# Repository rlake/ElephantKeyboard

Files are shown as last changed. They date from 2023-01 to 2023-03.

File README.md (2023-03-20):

# Elephant Keyboard
USB-C Number Pad Mechanical Keyboard

Featuring hot-swap Kailh sockets and RGB LED lighting.

Based on [Adafruit KB2040](https://www.adafruit.com/product/5302)

Keyboard Layout
---------------

Number pad from [Keyboard Layout Editor](http://www.keyboard-layout-editor.com)

```
["Num Lock","/","*","-"],
[{a:4,f:3},"7\nHome","8\n↑","9\nPgUp",{h:2},"+"],
["4\n←","5","6\n→"],
["1\nEnd","2\n↓","3\nPgDn",{h:2},"Enter"],
[{w:2},"0\nIns",".\nDel"]
```

Panel from [Swill Plate & Case Builder](http://builder.swillkb.com)

Options:
* mx t3
* cherry only
* edge padding 2.5mm
* corners 2.5mm

Firmware
--------

Based on [KMK](https://github.com/KMKfw/kmk_firmware)

With the following CircuitPython versions:

```
adafruit-circuitpython-adafruit_kb2040-en_GB-7.3.3.uf2
adafruit-circuitpython-bundle-7.x-mpy-20230129.zip
```

And these library files in `lib`:

```
adafruit_pixelbuf.mpy
neopixel.mpy
```

Parts
-----

* 0805 500R resistor QTY 1 (YAGEO RC0805JR-07470RL)
* 0805 100nF capacitor QTY 18 (YAGEO CC0805KRX7R9BB104)
* SC-70-5 level shifter buffer QTY 1 (TI SN74LV1T34DCKR)
* SOD-123 diode QTY 17 (ST 1N4148W)
* Kailh hot-swap sockets QTY 17 (CPG151101S11) [AdaFruit](https://www.adafruit.com/product/4958)
* Neopixel LEDs QTY 17 (SK6812MINI-E) [AdaFruit](https://www.adafruit.com/product/4960)

Plus KB2040 and any mechanical pieces for case i.e. bumpers (3M SJ-5312) and user choice of key caps and switches etc.

Panel was laser cut and powder coated 0.063" 5052 Aluminium by [SendCutSend](https://sendcutsend.com)

Other case parts laser cut 0.118" Acrylic, 0.030" chipboard and powder coated 0.063" 5052 Aluminium.

And finally 12mm M3 nylon or plastic nuts and bolts.

Build
-----
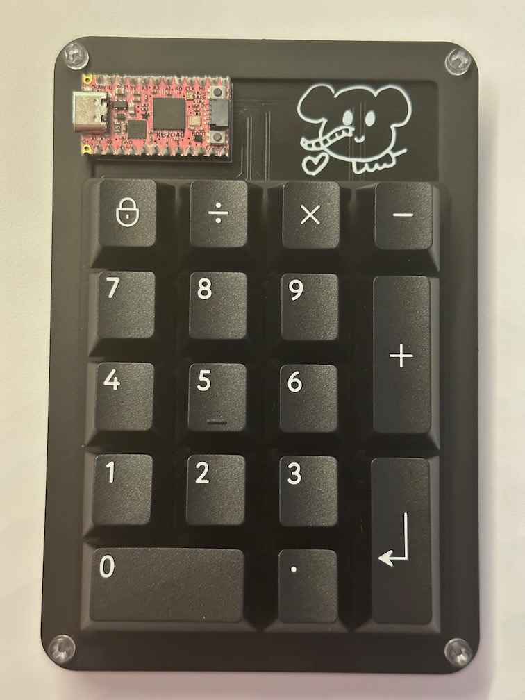
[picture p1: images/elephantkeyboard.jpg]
Elephant Keyboard


License Information
-------------------
The hardware is released under [Creative Commons ShareAlike 4.0 International](https://creativecommons.org/licenses/by-sa/4.0/).

Distributed as-is; no warranty is given.

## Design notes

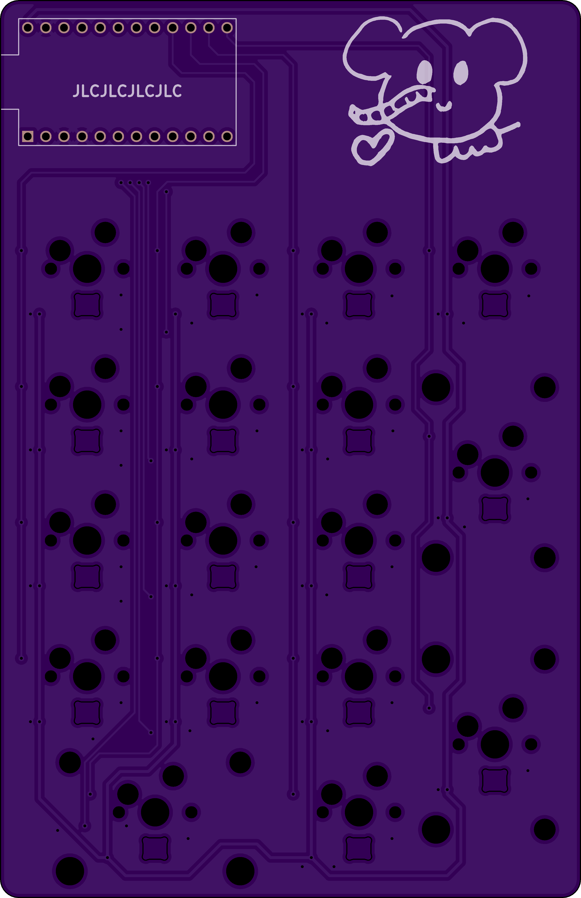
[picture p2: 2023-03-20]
images/elephantkeyboardt.png

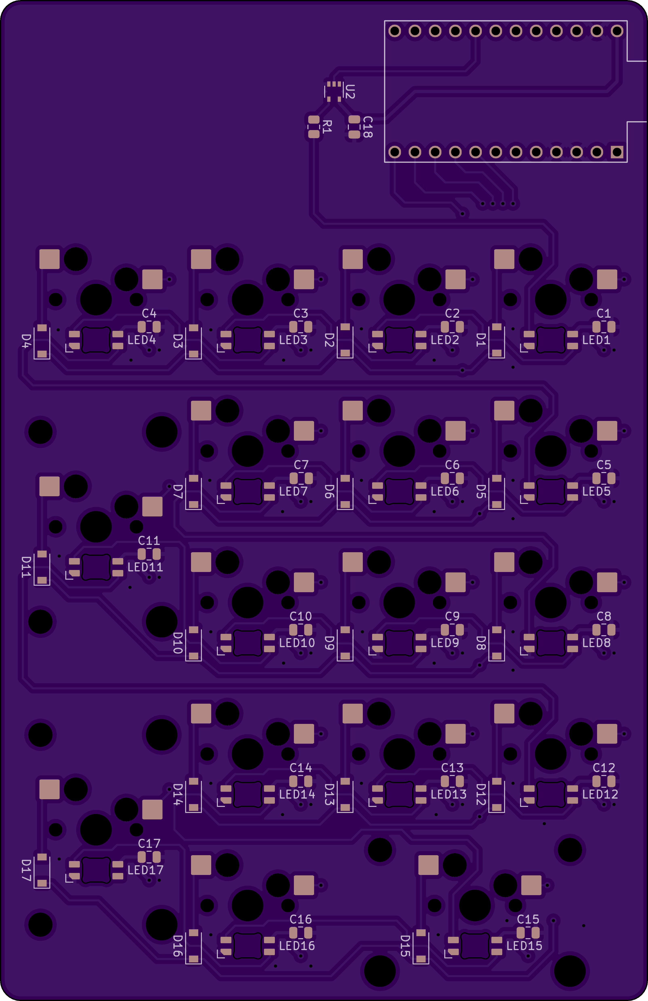
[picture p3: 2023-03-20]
images/elephantkeyboardb.png

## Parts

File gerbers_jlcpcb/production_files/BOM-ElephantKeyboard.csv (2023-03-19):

Comment | Designator | Footprint | LCSC
500R | R1 | R_0805_2012Metric | C114747
100nF | C1,C10,C11,C12,C13,C14,C15,C16,C17,C18,C2,C3,C4,C5,C6,C7,C8,C9 | C_0805_2012Metric | C49678
SN74LV1T34DCK | U2 | SOT-353_SC-70-5 | C78541
1N4148 | D1,D10,D11,D12,D13,D14,D15,D16,D17,D2,D3,D4,D5,D6,D7,D8,D9 | D_SOD-123 | C81598

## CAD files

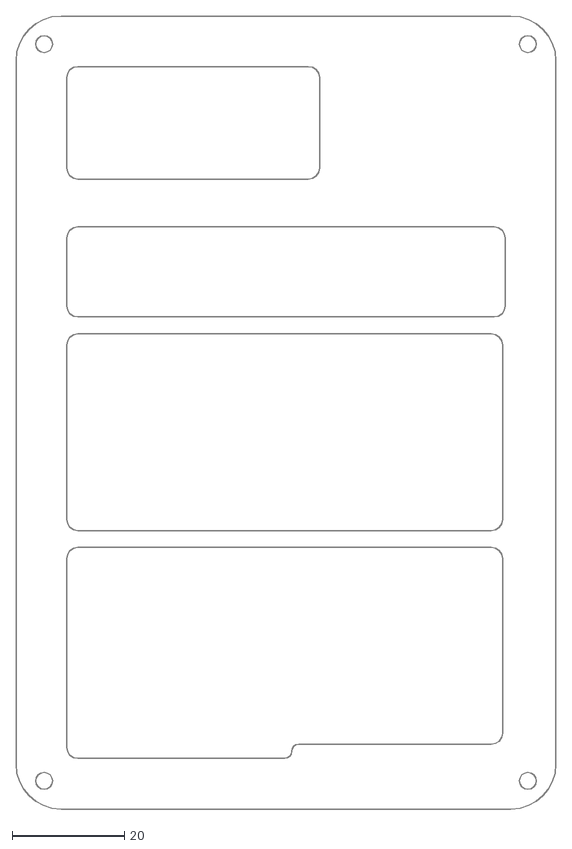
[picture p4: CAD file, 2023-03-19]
case/elephantkeyboard_case_layer0.dxf
96.0 x 141.0

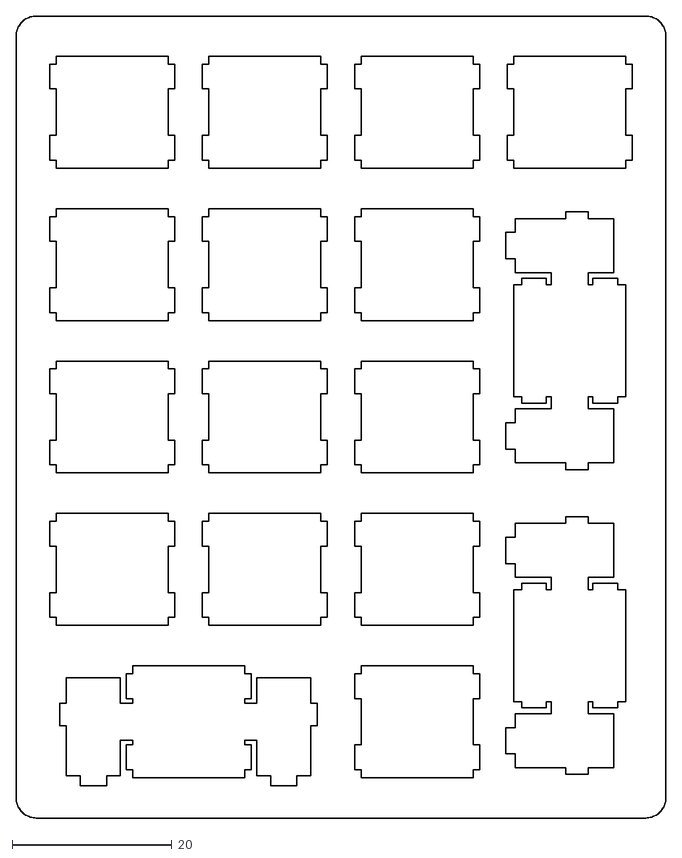
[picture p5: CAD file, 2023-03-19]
case/elephantkeyboard_panel_kerf0.dxf
81.2 x 100.3

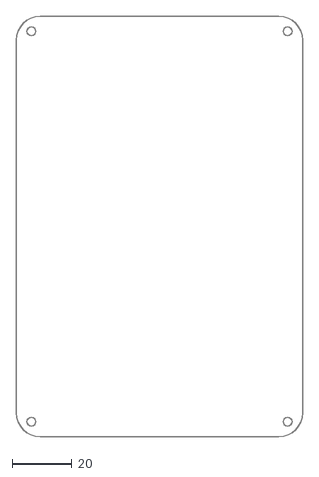
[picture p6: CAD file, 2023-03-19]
case/elephantkeyboard_case_layerbase.dxf
96.0 x 141.0

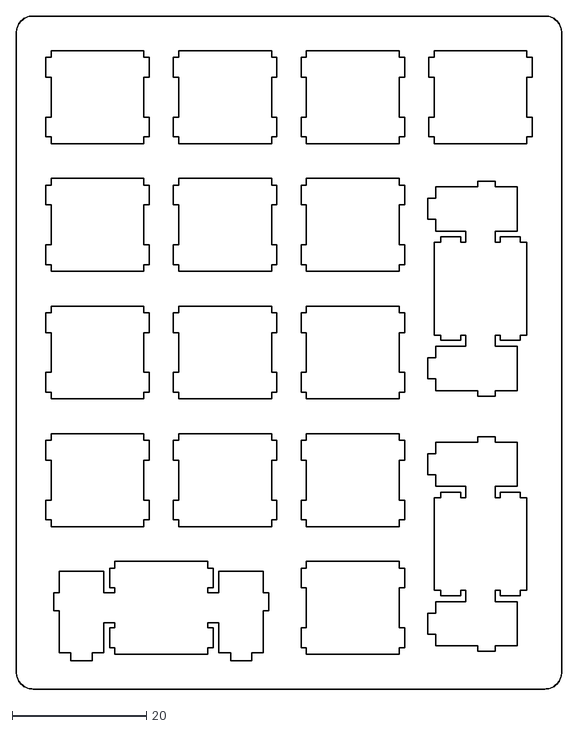
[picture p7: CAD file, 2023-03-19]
case/elephantkeyboard_panel.dxf
81.4 x 100.4

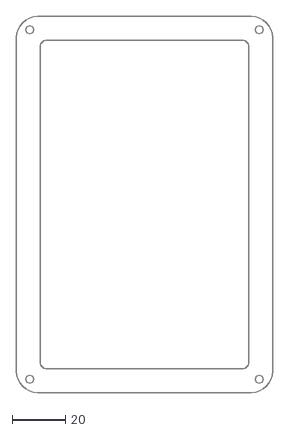
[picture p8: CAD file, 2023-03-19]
case/elephantkeyboard_case_layertop.dxf
96.0 x 141.0

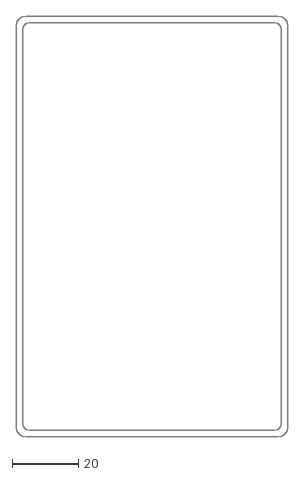
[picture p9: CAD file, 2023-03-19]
case/elephantkeyboard_case_layerpad.dxf
82.0 x 127.0

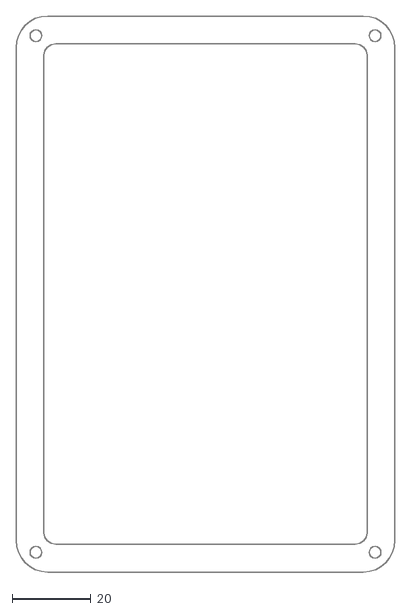
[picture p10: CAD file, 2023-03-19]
case/elephantkeyboard_case_layer1.dxf
96.0 x 141.0

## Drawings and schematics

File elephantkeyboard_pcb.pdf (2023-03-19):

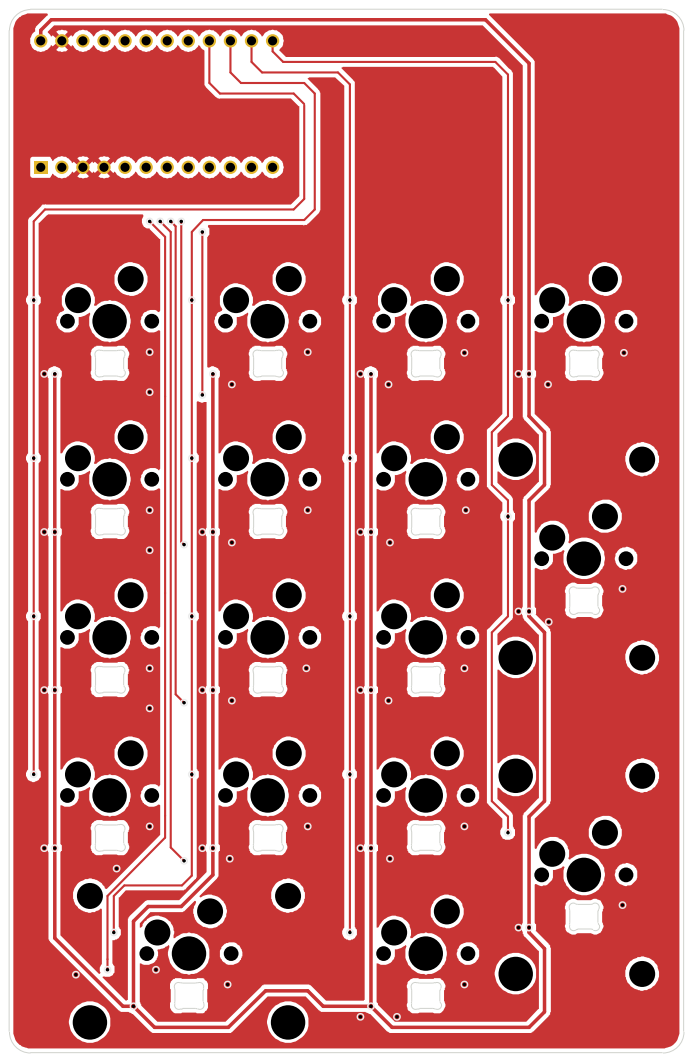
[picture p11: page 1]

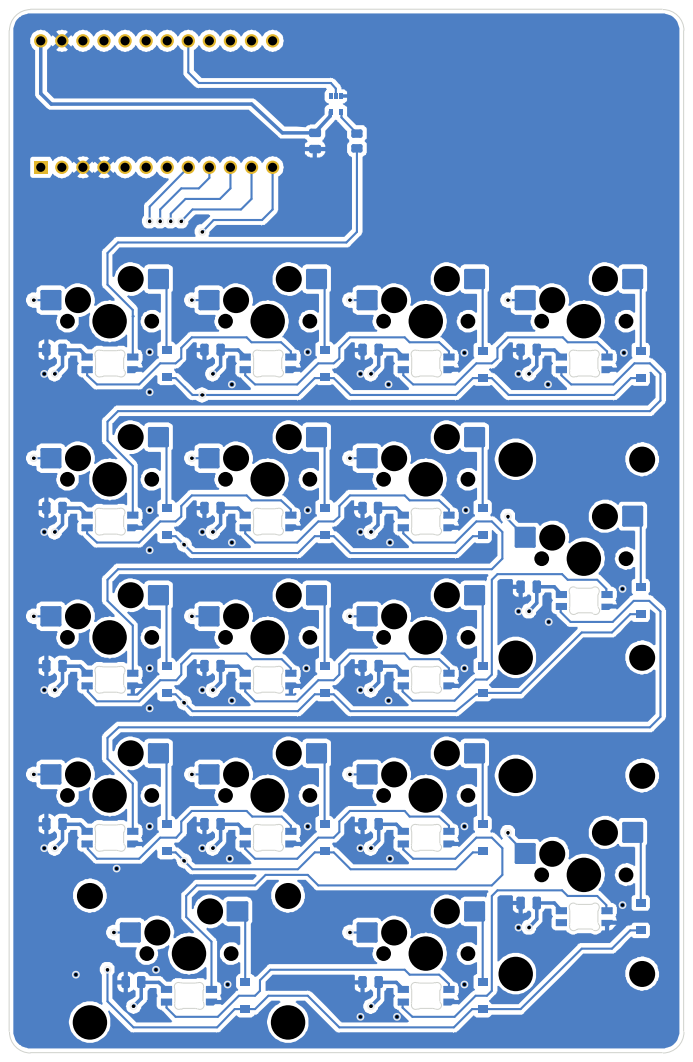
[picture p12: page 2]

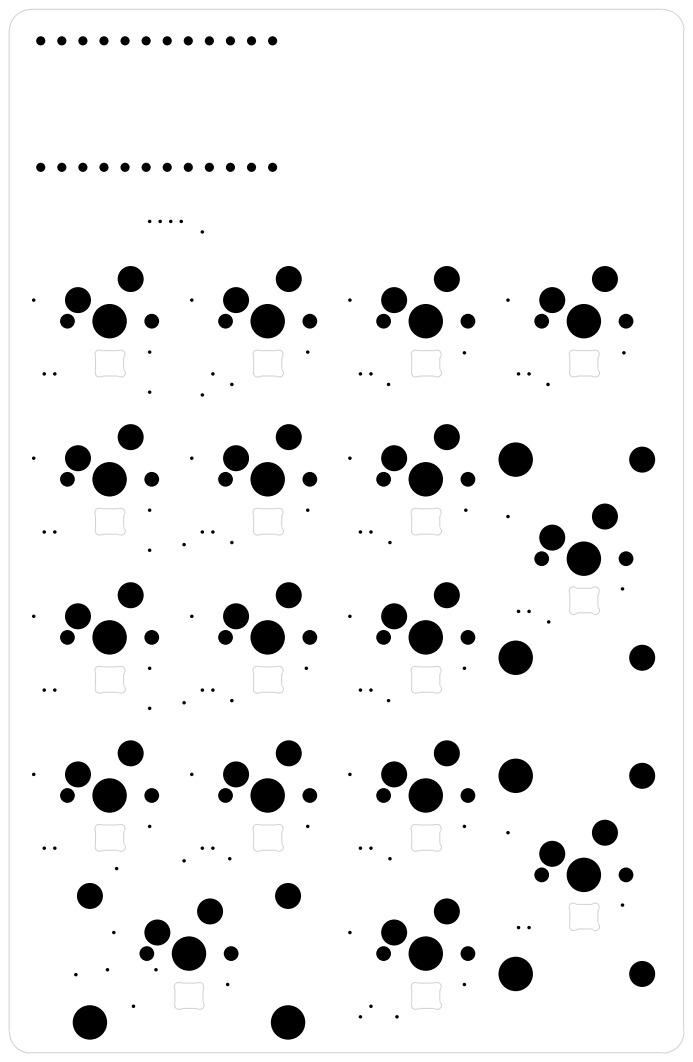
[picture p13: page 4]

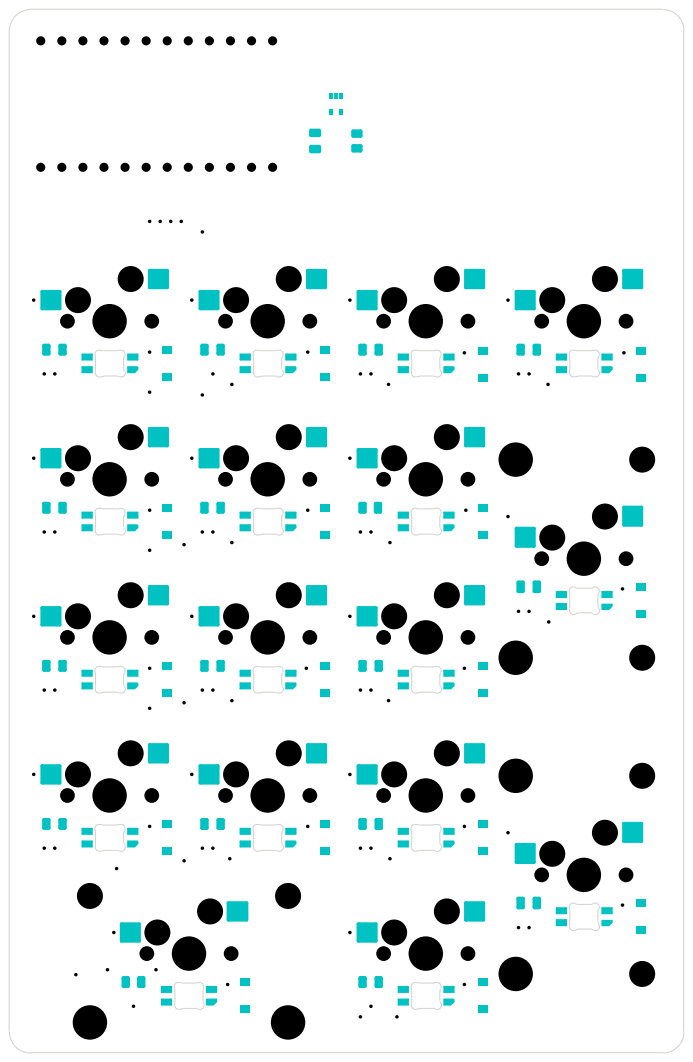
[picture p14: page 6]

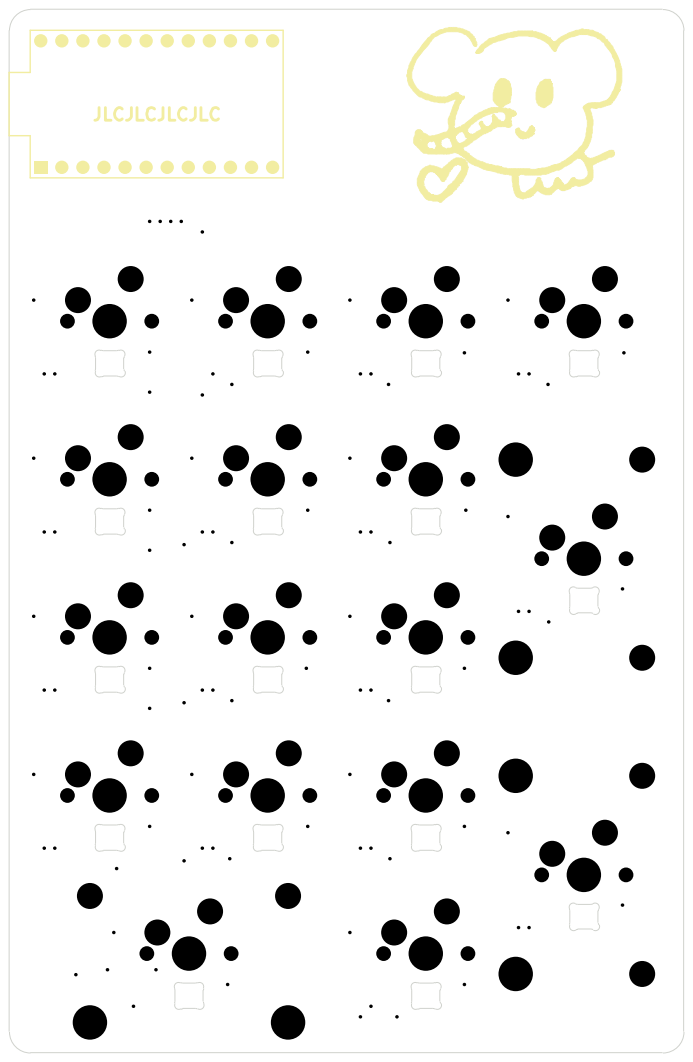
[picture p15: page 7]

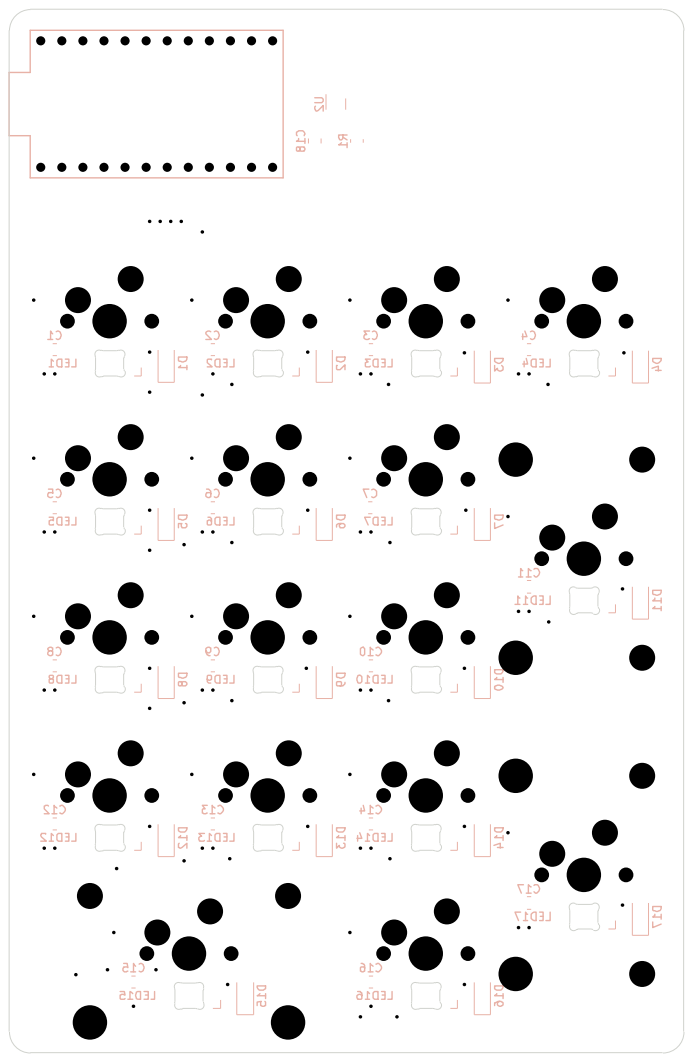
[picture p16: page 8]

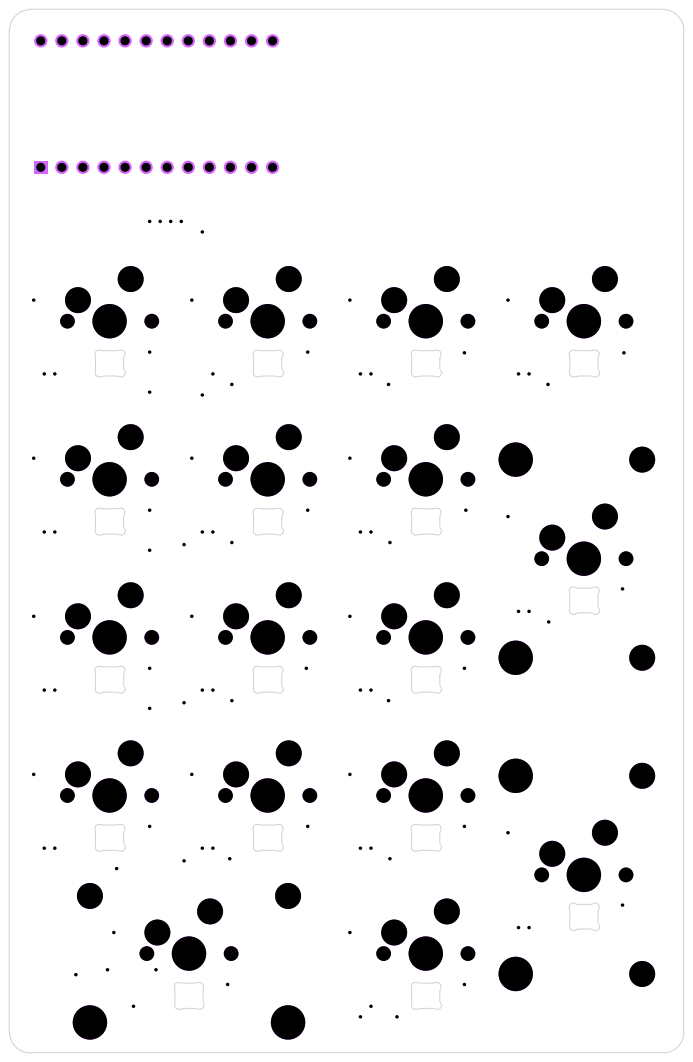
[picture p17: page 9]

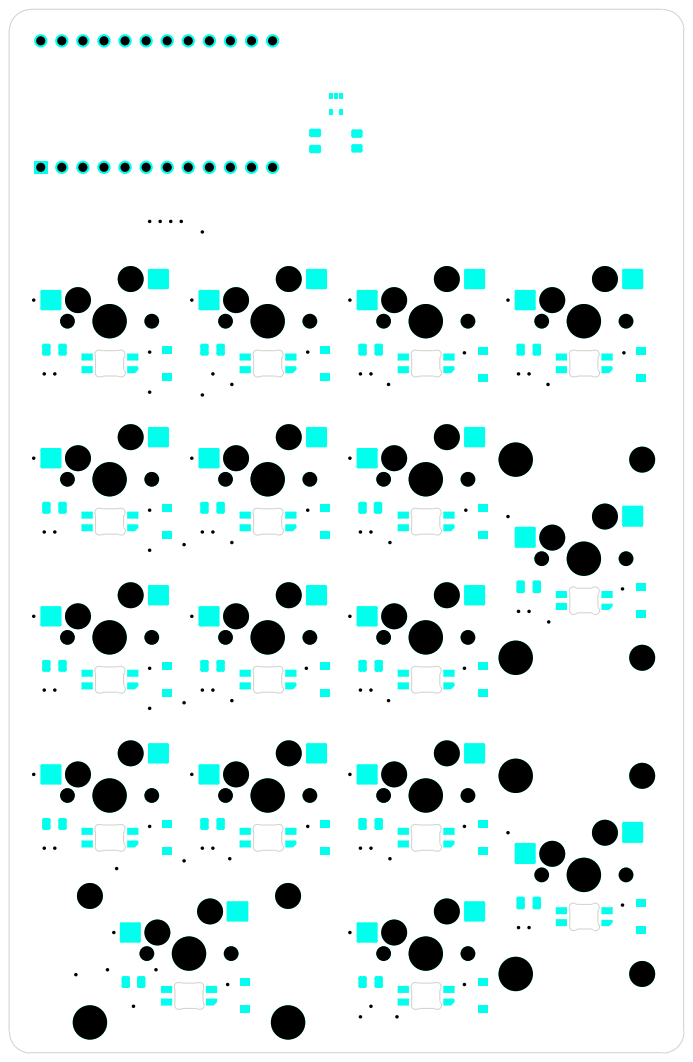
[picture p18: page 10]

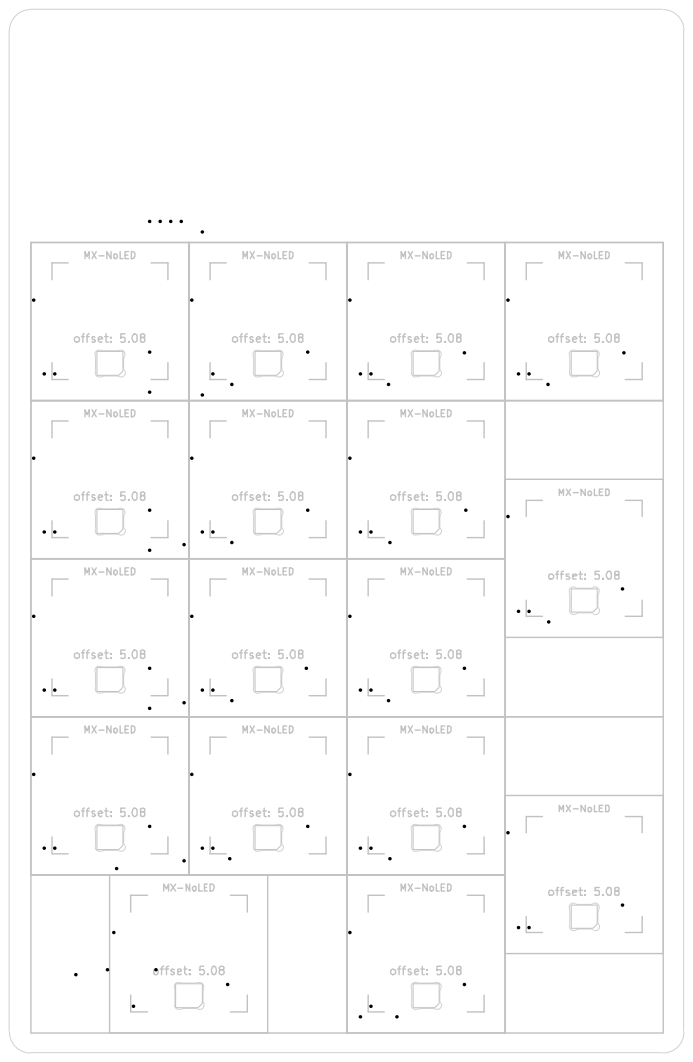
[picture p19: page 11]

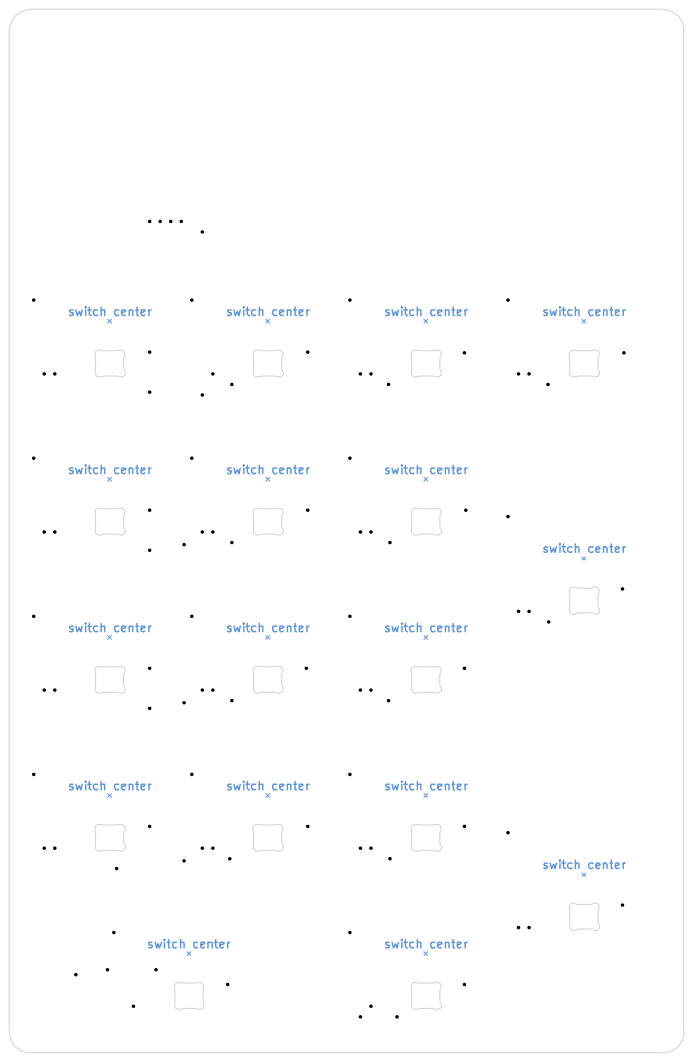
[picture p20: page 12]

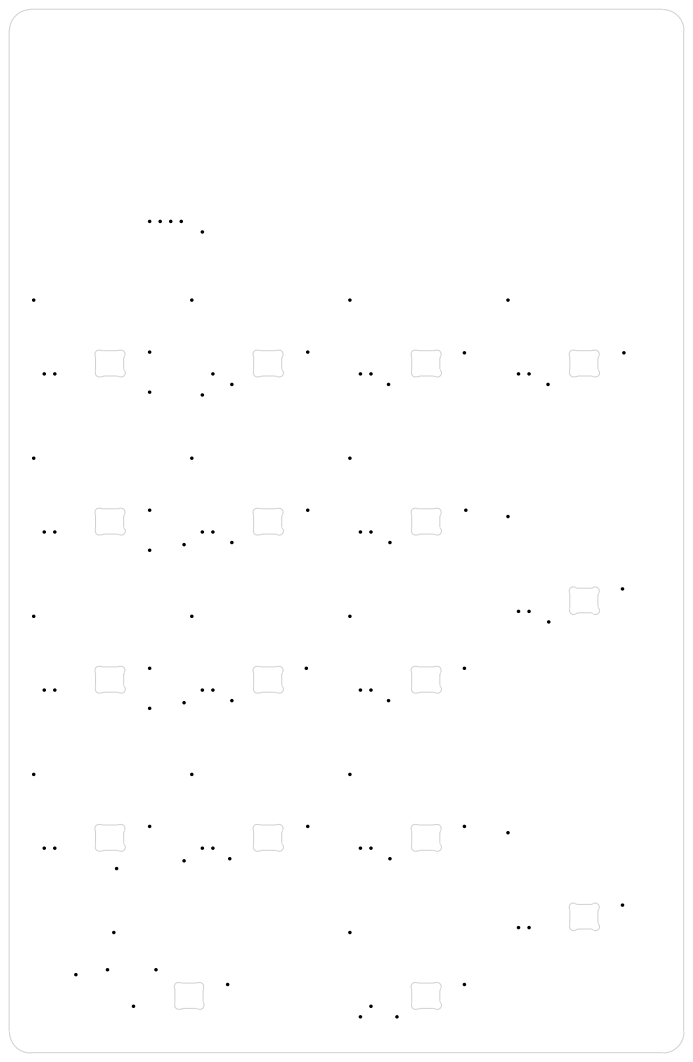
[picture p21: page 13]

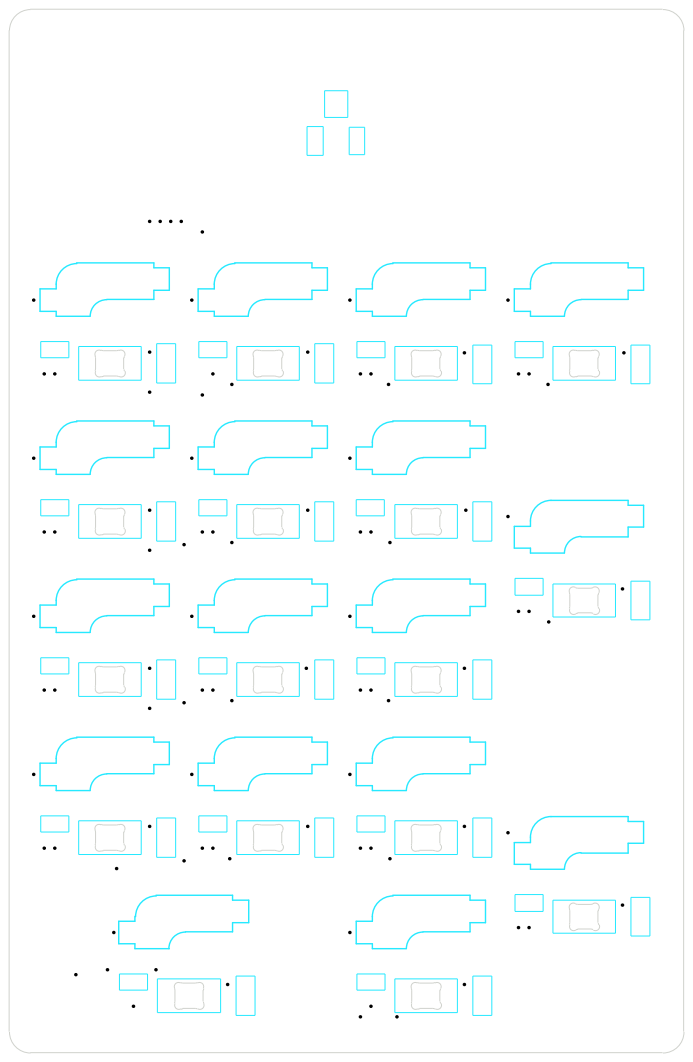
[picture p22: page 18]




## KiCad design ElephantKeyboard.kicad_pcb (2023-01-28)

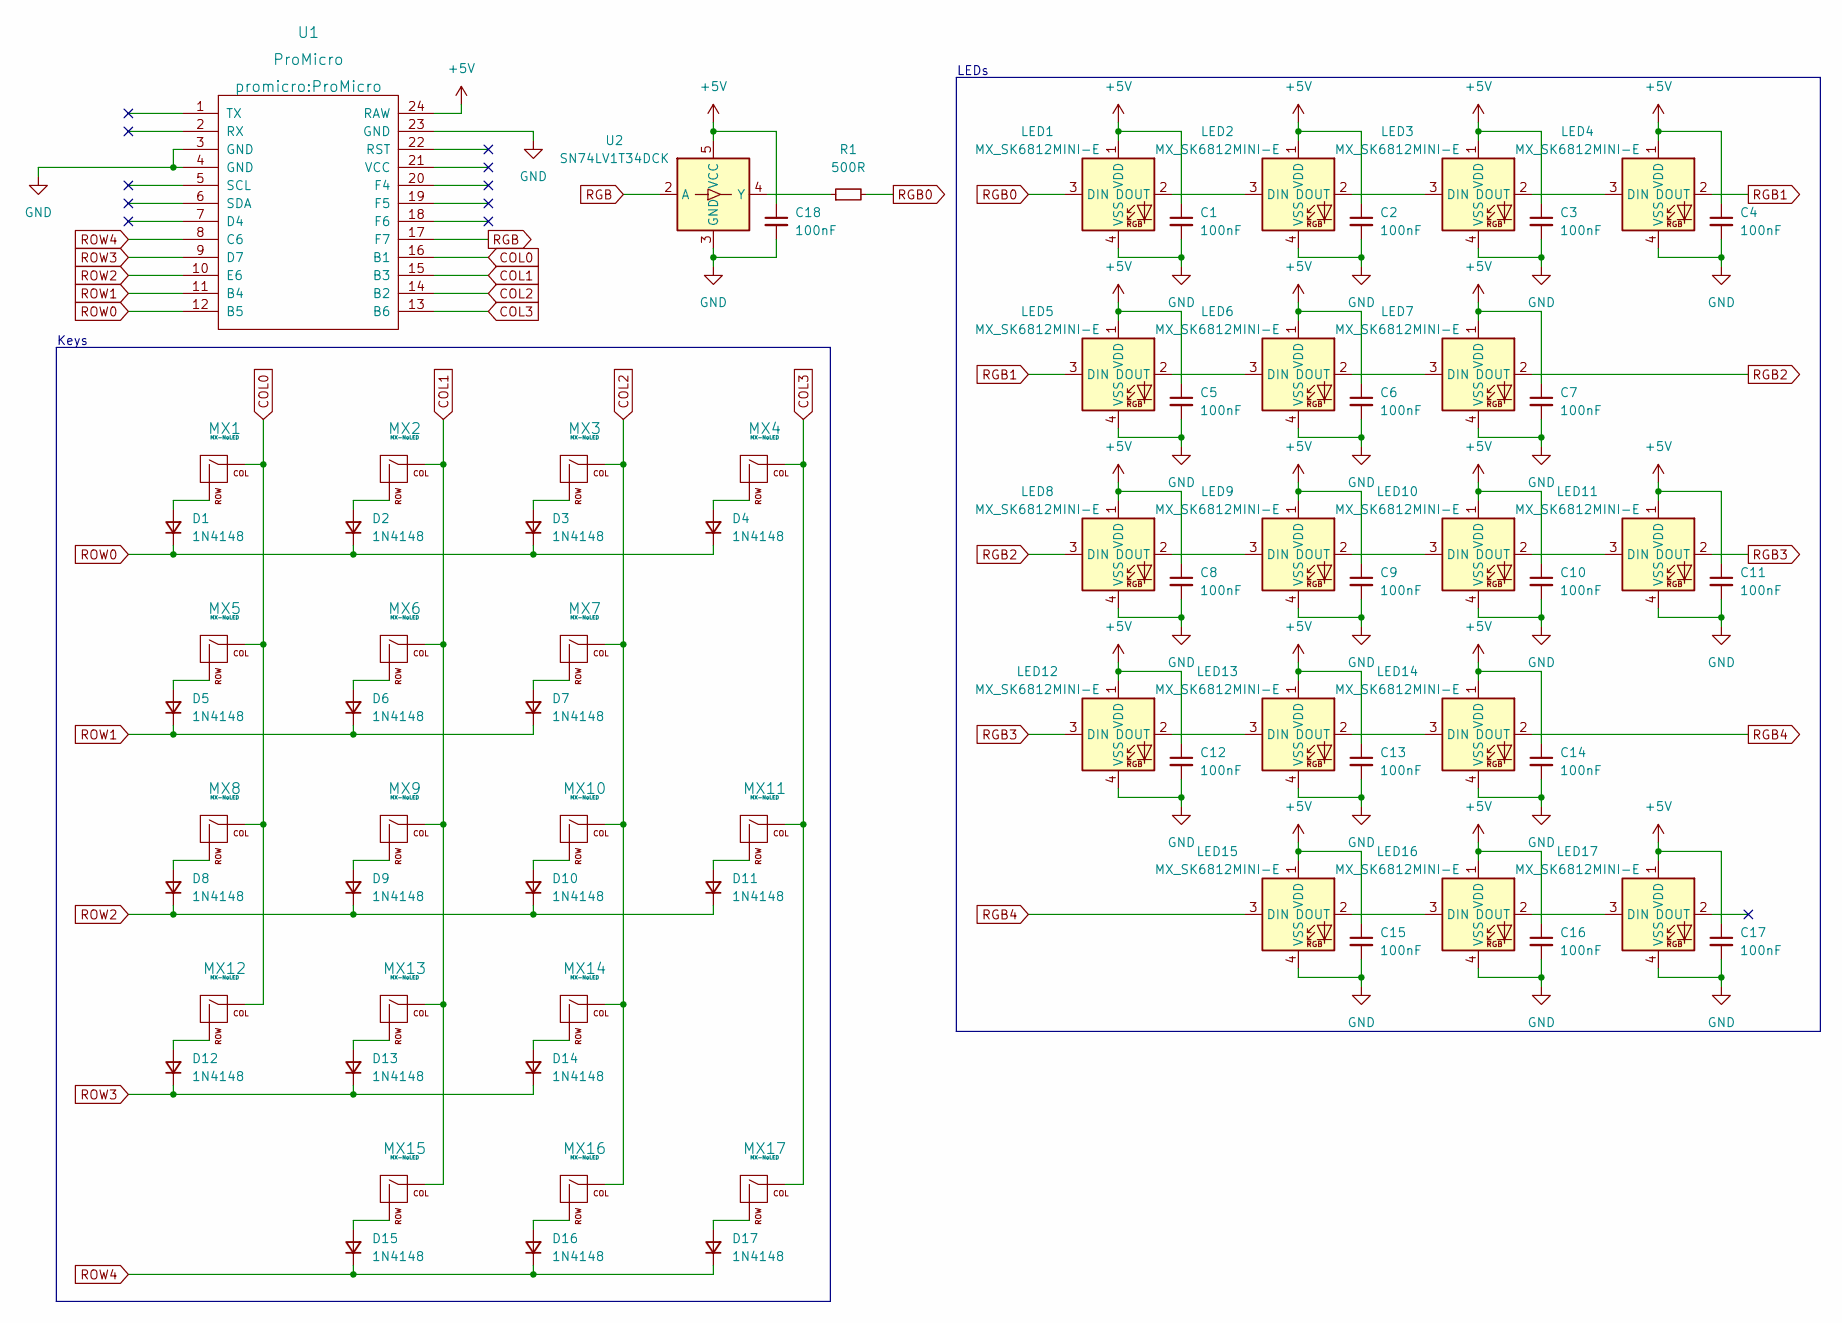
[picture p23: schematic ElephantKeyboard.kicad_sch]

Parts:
C1: 100nF
C2, C3, C4, C5, C6, C7, C8, C9, C10, C11, C12, C13, C14, C15, C16, C17, C18: 100nF; C_0805_2012Metric
D1: 1N4148
D2, D3, D4, D5, D6, D7, D8, D9, D10, D11, D12, D13, D14, D15, D16, D17: 1N4148; D_SOD-123
LED1, LED2, LED3, LED4, LED5, LED6, LED7, LED8, LED9, LED10, LED11, LED12, LED13, LED14, LED15, LED16, LED17: MX_SK6812MINI-E; LED_MX_6028R
MX1, MX2, MX3, MX4, MX5, MX6, MX7, MX8, MX9, MX10, MX12, MX13, MX14, MX16: MX-NoLED; MX-Hotswap-1U
MX11, MX17: MX-NoLED; MX-Hotswap-2U-Vertical
MX15: MX-NoLED; MX-Hotswap-2U
R1: 500R
U1: ProMicro
U2: SN74LV1T34DCK; SOT-353_SC-70-5

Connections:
+5V: C1.1, C2.1, C3.1, C4.1, C5.1, C6.1, C7.1, C8.1, C9.1, C10.1, C11.1, C12.1, C13.1, C14.1, C15.1, C16.1, C17.1, C18.1, LED1.1 (VDD), LED2.1 (VDD), LED3.1 (VDD), LED4.1 (VDD), LED5.1 (VDD), LED6.1 (VDD), LED7.1 (VDD), LED8.1 (VDD), LED9.1 (VDD), LED10.1 (VDD), LED11.1 (VDD), LED12.1 (VDD), LED13.1 (VDD), LED14.1 (VDD), LED15.1 (VDD), LED16.1 (VDD), LED17.1 (VDD), U1.24 (RAW), U2.5 (VCC)
COL0: MX1.1 (COL), MX5.1 (COL), MX8.1 (COL), MX12.1 (COL), U1.16 (B1)
COL1: MX2.1 (COL), MX6.1 (COL), MX9.1 (COL), MX13.1 (COL), MX15.1 (COL), U1.15 (B3)
COL2: MX3.1 (COL), MX7.1 (COL), MX10.1 (COL), MX14.1 (COL), MX16.1 (COL), U1.14 (B2)
COL3: MX4.1 (COL), MX11.1 (COL), MX17.1 (COL), U1.13 (B6)
GND: C1.2, C2.2, C3.2, C4.2, C5.2, C6.2, C7.2, C8.2, C9.2, C10.2, C11.2, C12.2, C13.2, C14.2, C15.2, C16.2, C17.2, C18.2, LED1.4 (VSS), LED2.4 (VSS), LED3.4 (VSS), LED4.4 (VSS), LED5.4 (VSS), LED6.4 (VSS), LED7.4 (VSS), LED8.4 (VSS), LED9.4 (VSS), LED10.4 (VSS), LED11.4 (VSS), LED12.4 (VSS), LED13.4 (VSS), LED14.4 (VSS), LED15.4 (VSS), LED16.4 (VSS), LED17.4 (VSS), U1.3 (GND), U1.4 (GND), U1.23 (GND), U2.3 (GND)
unnamed: D1.2 (A), MX1.2 (ROW)
unnamed: D4.2 (A), MX4.2 (ROW)
unnamed: D8.2 (A), MX8.2 (ROW)
unnamed: D9.2 (A), MX9.2 (ROW)
unnamed: D13.2 (A), MX13.2 (ROW)
unnamed: D15.2 (A), MX15.2 (ROW)
unnamed: LED1.2 (DOUT), LED2.3 (DIN)
unnamed: LED2.2 (DOUT), LED3.3 (DIN)
unnamed: LED3.2 (DOUT), LED4.3 (DIN)
unnamed: LED6.2 (DOUT), LED7.3 (DIN)
unnamed: LED5.2 (DOUT), LED6.3 (DIN)
unnamed: LED8.2 (DOUT), LED9.3 (DIN)
unnamed: LED10.2 (DOUT), LED11.3 (DIN)
unnamed: LED9.2 (DOUT), LED10.3 (DIN)
unnamed: LED12.2 (DOUT), LED13.3 (DIN)
unnamed: LED13.2 (DOUT), LED14.3 (DIN)
unnamed: LED15.2 (DOUT), LED16.3 (DIN)
unnamed: LED16.2 (DOUT), LED17.3 (DIN)
unnamed: D2.2 (A), MX2.2 (ROW)
unnamed: D3.2 (A), MX3.2 (ROW)
unnamed: D5.2 (A), MX5.2 (ROW)
unnamed: D6.2 (A), MX6.2 (ROW)
unnamed: D7.2 (A), MX7.2 (ROW)
unnamed: D10.2 (A), MX10.2 (ROW)
unnamed: D11.2 (A), MX11.2 (ROW)
unnamed: D12.2 (A), MX12.2 (ROW)
unnamed: D14.2 (A), MX14.2 (ROW)
unnamed: D16.2 (A), MX16.2 (ROW)
unnamed: D17.2 (A), MX17.2 (ROW)
unnamed: R1.1, U2.4 (Y)
RGB: U1.17 (F7), U2.2 (A)
RGB0: LED1.3 (DIN), R1.2
RGB1: LED4.2 (DOUT), LED5.3 (DIN)
RGB2: LED7.2 (DOUT), LED8.3 (DIN)
RGB3: LED11.2 (DOUT), LED12.3 (DIN)
RGB4: LED14.2 (DOUT), LED15.3 (DIN)
ROW0: D1.1 (K), D2.1 (K), D3.1 (K), D4.1 (K), U1.12 (B5)
ROW1: D5.1 (K), D6.1 (K), D7.1 (K), U1.11 (B4)
ROW2: D8.1 (K), D9.1 (K), D10.1 (K), D11.1 (K), U1.10 (E6)
ROW3: D12.1 (K), D13.1 (K), D14.1 (K), U1.9 (D7)
ROW4: D15.1 (K), D16.1 (K), D17.1 (K), U1.8 (C6)

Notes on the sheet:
Keys
LEDs

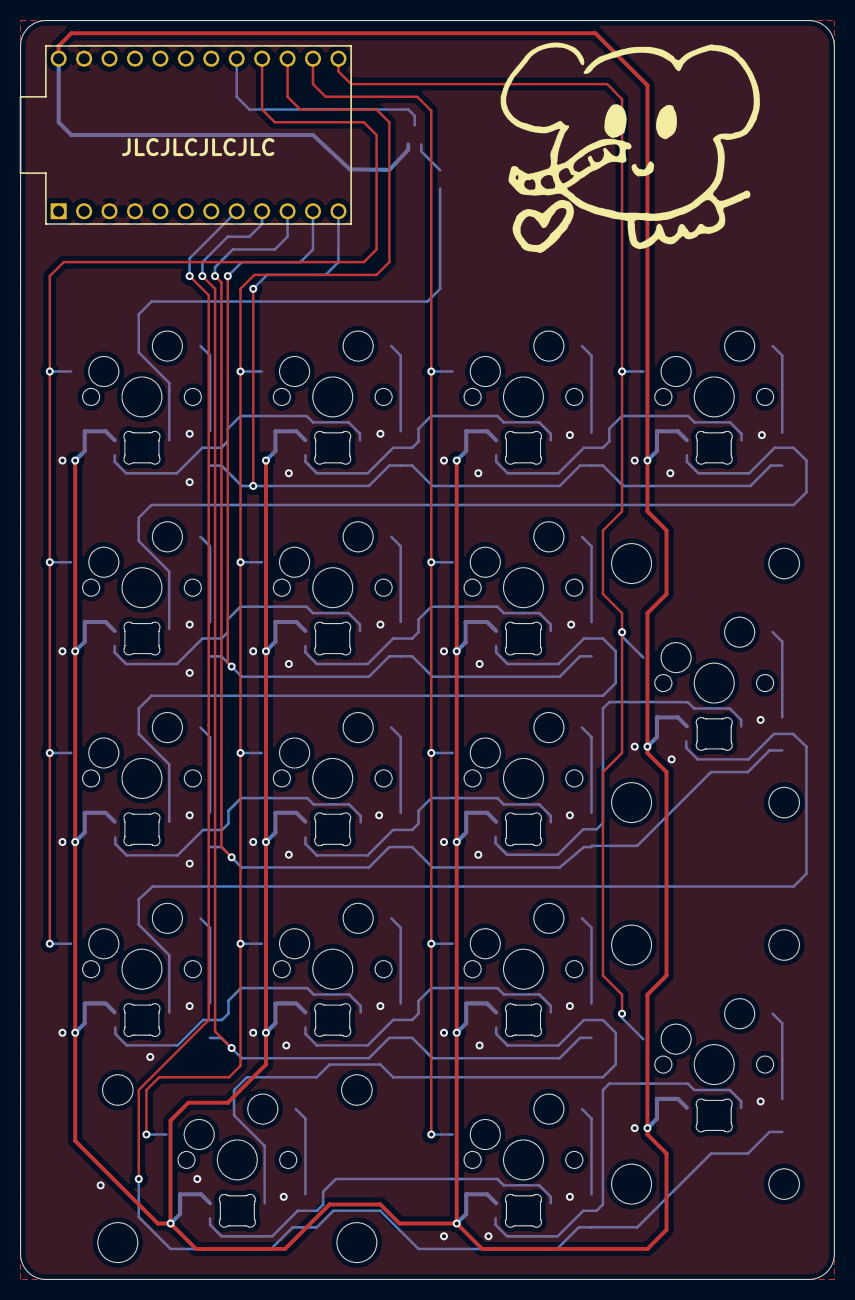
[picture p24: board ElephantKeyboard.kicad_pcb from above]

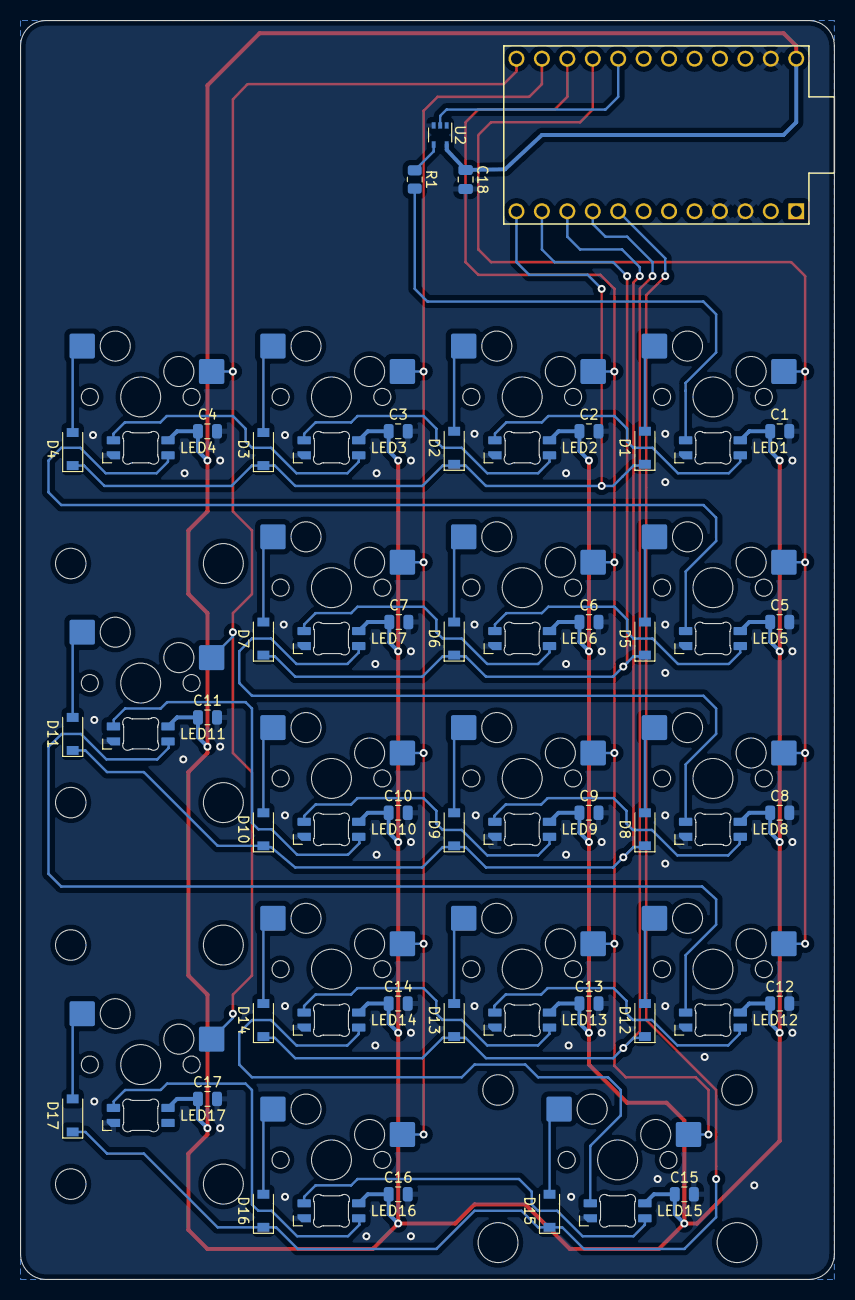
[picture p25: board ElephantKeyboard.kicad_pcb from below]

Board: 2 copper layers, 81.3 x 125.7 mm, 72 parts (54 on the bottom side), 47 nets.

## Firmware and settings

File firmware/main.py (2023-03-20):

import board

from kb import KMKKeyboard

from kmk.extensions.lock_status import LockStatus
from kmk.extensions.media_keys import MediaKeys
from kmk.extensions.RGB import RGB, AnimationModes
from kmk.handlers.sequences import simple_key_sequence
from kmk.keys import KC
from kmk.modules.layers import Layers

keyboard = KMKKeyboard()

layers_ext = Layers()
keyboard.modules.append(layers_ext)

media_keys = MediaKeys()
keyboard.extensions.append(media_keys)

rgb_ext = RGB(
    pixel_pin=board.A0,
    num_pixels=17,
    val_limit=4,
    val_default=4,
    animation_mode=AnimationModes.BREATHING_RAINBOW
)
keyboard.extensions.append(rgb_ext)

class LEDLockStatus(LockStatus):
    def __init__(self, rgb_ext):
        super().__init__()
        self._rgb_ext = rgb_ext

    def set_lock_leds(self):
        if self.get_num_lock():
            pass
            #leds.set_brightness(50, leds=[0])
            #self._rgb_ext.val = self._rgb_ext.val_default
        else:
            pass
            #self._rgb_ext.val = 0
            #leds.set_brightness(0, leds=[0])

    def after_hid_send(self, sandbox):
        super().after_hid_send(sandbox)
        if self.report_updated:
            self.set_lock_leds()

keyboard.extensions.append(LEDLockStatus(rgb_ext))

num_lock_sequence = simple_key_sequence((KC.NLCK, KC.RGB_TOG))

keyboard.debug_enabled = True

# Cleaner key names
_______ = KC.TRNS
XXXXXXX = KC.NO

keyboard.keymap = [
    [
        num_lock_sequence,
                 KC.PSLS, KC.PAST, KC.PMNS,
        KC.P7,   KC.P8,   KC.P9,   _______,
        KC.P4,   KC.P5,   KC.P6,   KC.PPLS,
        KC.P1,   KC.P2,   KC.P3,   _______,
        _______, KC.P0, KC.PDOT,   KC.PENT,
        ]
]

if __name__ == '__main__':
    keyboard.go()

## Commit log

2023-01-22 Initial KiCad project
    [ElephantKeyboard.kicad_pcb, ElephantKeyboard.kicad_sch]
2023-01-22 ai03 MX v2 footprint library
2023-01-22 ai03 ProMicro symbol and footprint library
2023-01-22 marbastlib symbol and footprint library
2023-01-28 Elephant Keyboard
    [ElephantKeyboard.kicad_pcb, ElephantKeyboard.kicad_sch]
2023-03-19 Schematics and PCB PDFs
2023-03-19 Case design files
    [elephantkeyboard_case_layer0.dxf, elephantkeyboard_case_layer1.dxf, elephantkeyboard_case_layerbase.dxf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]
2023-03-20 Images for PCB and build
